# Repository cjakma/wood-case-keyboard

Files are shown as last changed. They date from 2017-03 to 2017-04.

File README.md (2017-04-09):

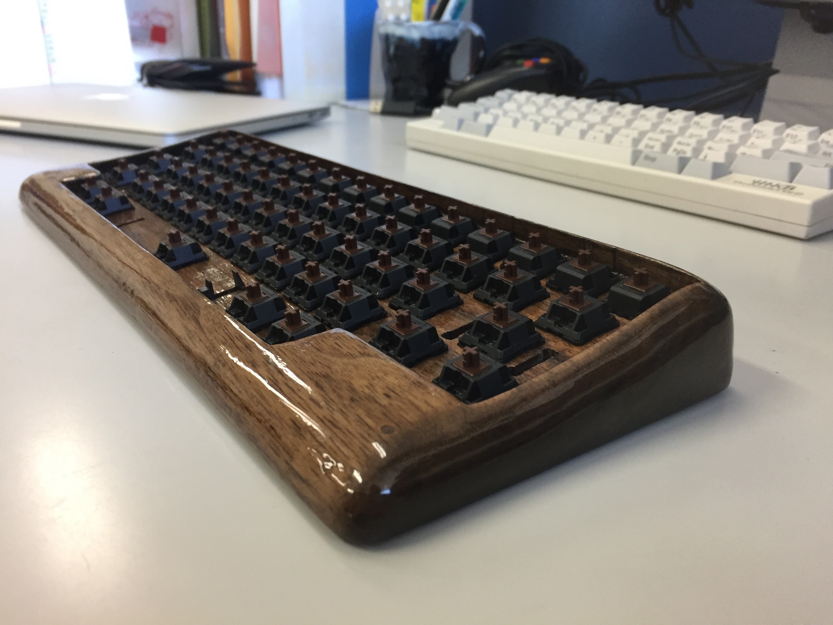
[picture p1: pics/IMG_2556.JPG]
look0

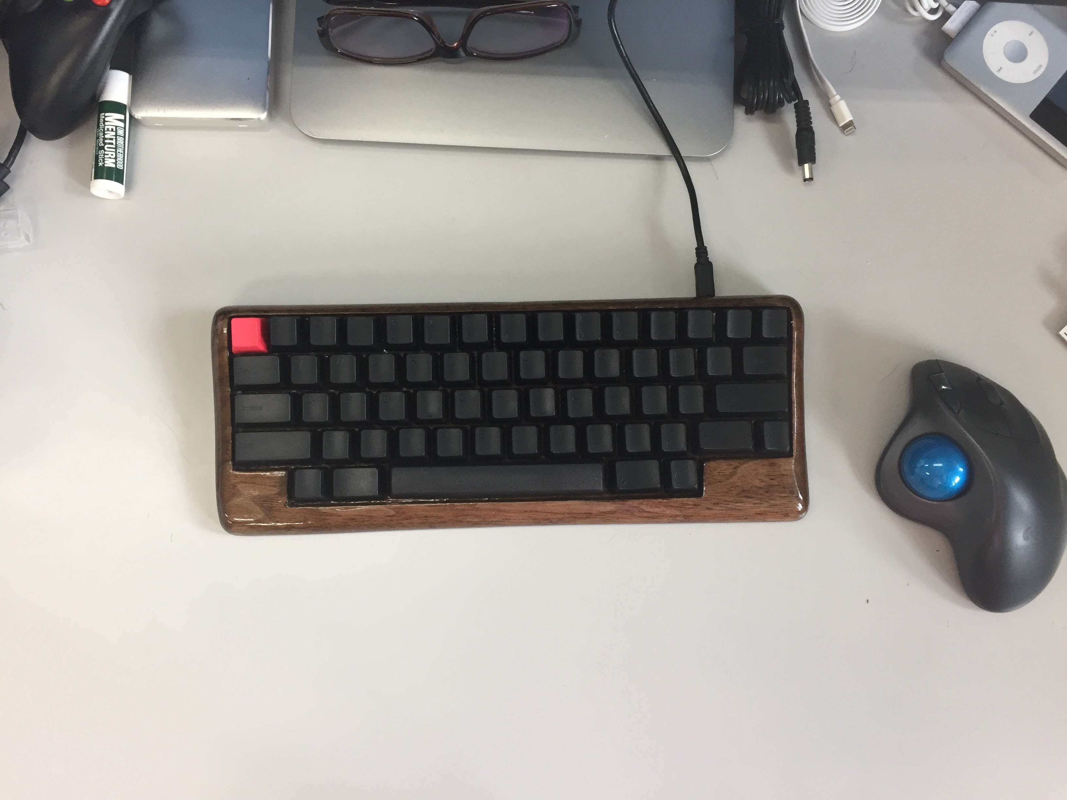
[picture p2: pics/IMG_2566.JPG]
look1

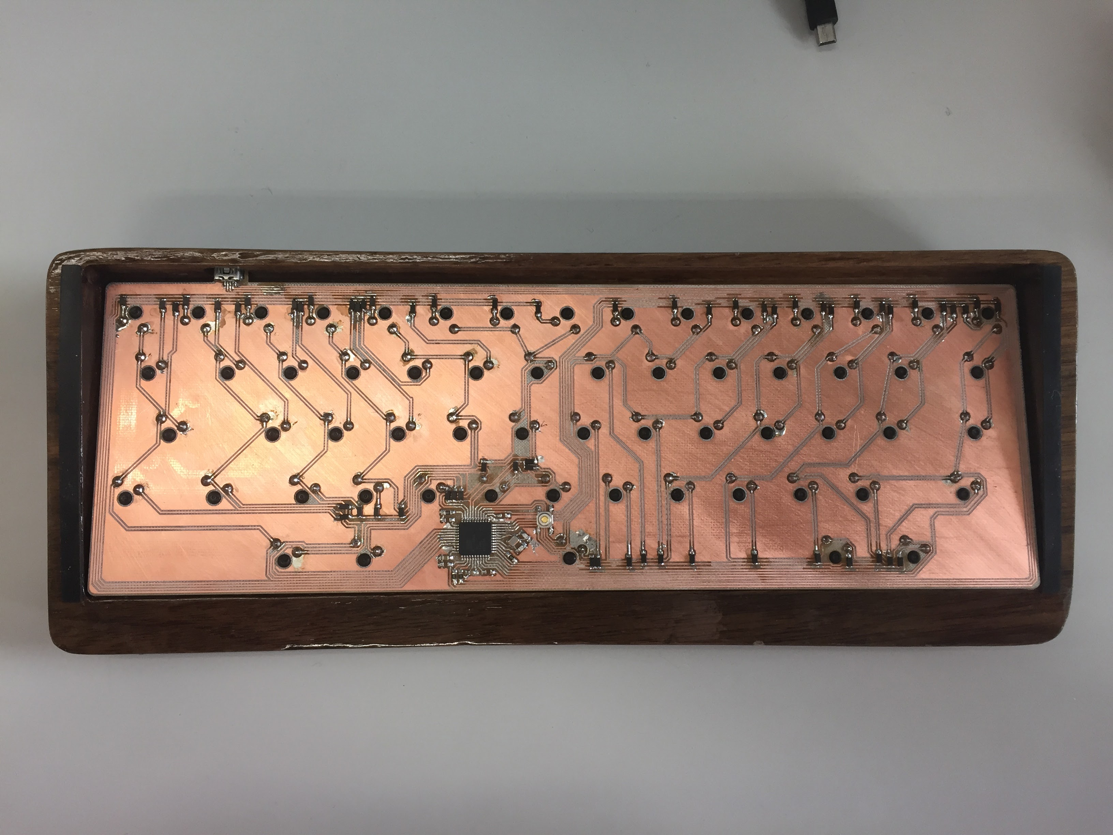
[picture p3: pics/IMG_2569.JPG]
look2


# Brief
This is a hobby project, to make a copy of HHKB made of wood,
but not limited to it. It is fully customizable, parameterized
toolchain to generate a keyboard case.

## Features
- Made of wood
- Nice curved shape
- Customizable layout and shape (compatible with <http://www.keyboard-layout-editor.com/>)
- Open bottom (it minimizes overall height and you can show off your beautiful PCB!)
- Compatible with most PCBs built with SMD components(?)

## BOM
| Name | Quantities | Price | Note |
| --- | --- | ----- | --- |
| 36x130x330mm walnut block | 1 | 2,080 JPY | <http://shop.woodworks-marutoku.com/products/muku/item/m003.php> |
| Cherry mx brown switches  | 60 | 4,640 JPY | |
| PCB | 1 | 2,908 JPY | DIY <https://github.com/jinhwanlazy/hhkb-pcb> |
| Keycaps | 1 | 50 USD | Special order from <http://www.maxkeyboard.com/> |

# Dependancies
- python3
- [python-shapely](https://pypi.python.org/pypi/Shapely)
- [Openscad](http://www.openscad.org/) - nightly version is recommended
- [OskarLinde/scad-utils](https://github.com/OskarLinde/scad-utils)
- [openscad/list-comprehension-demos](https://github.com/openscad/list-comprehension-demos)

# Build
Open `model/common.sacd` and modify parameters. You have to set `block_size`
properly even if you don't want to change anything. See
[Customization](#customization) section for details.

Following command will generate all 3D and 2D models you need, in
`stl` and `dxf` format, under `out` directory. Once you excecute `make` 
successfuly, you can open `model/preview.scad` and see how it will look
like.

    git clone https://github.com/jinhwanlazy/wood-case-keyboard
    cd wood-case-keyboard
    make

In OSX, you have to specify full path of openscad.

    make SCAD=/Applications/OpenSCAD.app/Contents/MacOS/OpenSCAD

# Customization
## Layout
Layout definitions are located under `layout` directory. They are 
compatible with <http://www.keyboard-layout-editor.com/>. 
You can feed one of them like this.

    make clean
    make LAYOUT=layout/plank.layout

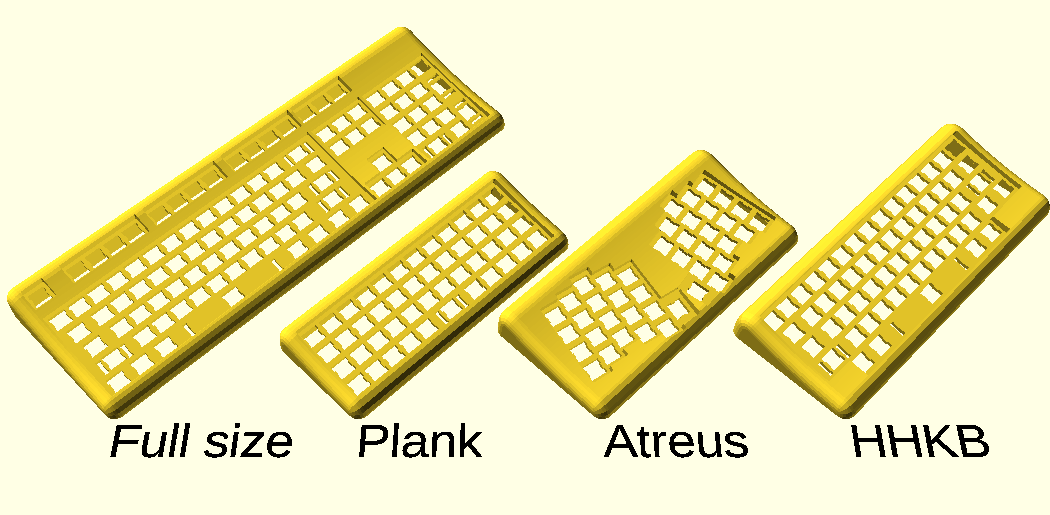
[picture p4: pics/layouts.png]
layouts


## Parameters
preparing...

# Instruction
I used a [Shapeoko1](https://www.shapeoko.com/shapeoko1.html) for milling
, and [PyCam](http://pycam.sourceforge.net/) to generate 
toolpaths. And it was painfull job.
I have spent a lot of time to properly calibrate machine but
still encountered number of hardware problems(slipping bits, burning wood, missing steps, etc). 
I had to manually edit gcodes generated by PyCam. sometimes I forgot to do it,
and it came back with disasters. Most of them are covered with sanding process,
but some were unreversible, especially, you can see a hole at bottom right corner of the
case in the first picture.
I had to make monkeypatchs everytime something goes wrong. 
I highly recommend you to use commercial grade toolchain or just talk with manufacturer. 
I'll leave here very brief steps I have followed, rather than full instruction. 

0. I started with 330x130x34mm walnut block.
1. Print `back_holder.stl` and `tilt_holder.stl` with 3D printer.
2. Fix wood block on CNC mill, and carve it with `base.stl`. I had to split it
two pieces, due to limitaion of build space. 
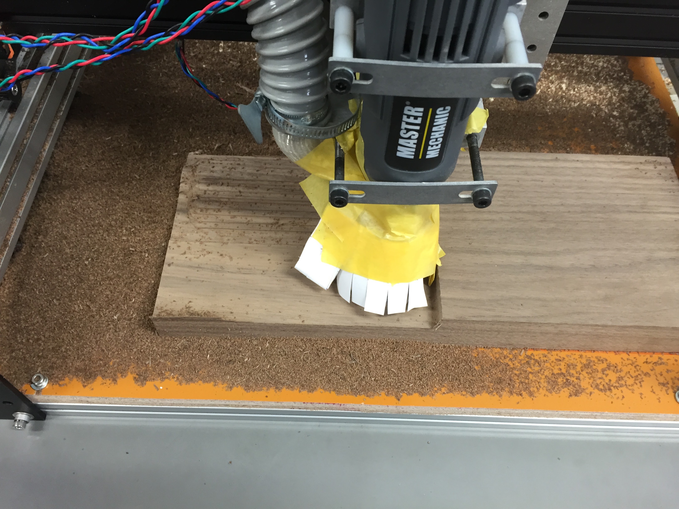
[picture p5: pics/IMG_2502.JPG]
ins2

3. Fix a pair of `tilt_holder` with screw at bottom of the wood block.
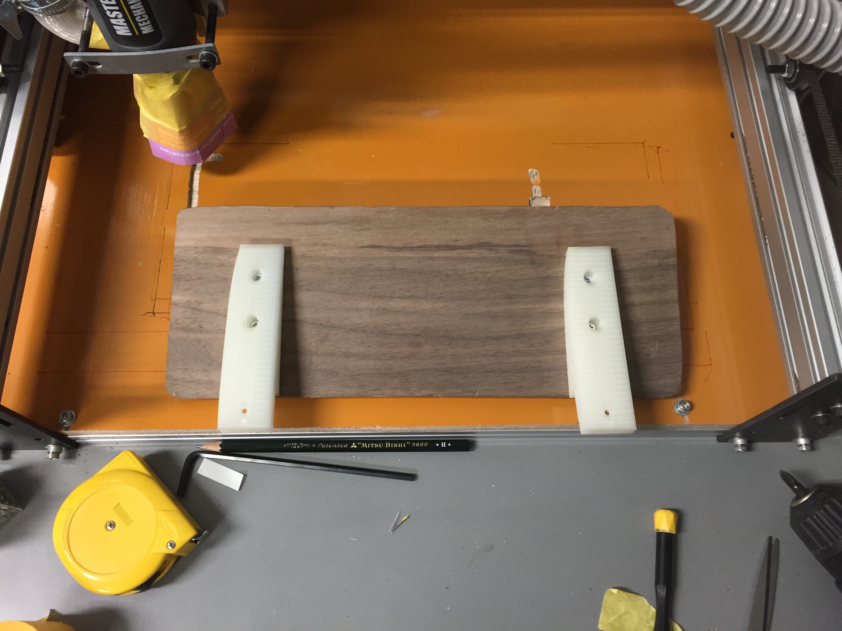
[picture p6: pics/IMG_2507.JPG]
ins3

4. Place wood block again, and cut it with `top_cutout.dxf`.
Cut depth is `lip_depth`mm from the highest point of the woodblock. It is
defined in `common.scad`.
The size of the model is arbitrary. Ignore the contour.
You have to cutout only pockets of the model.
The origin of the model is set to bottom leftmost key position.
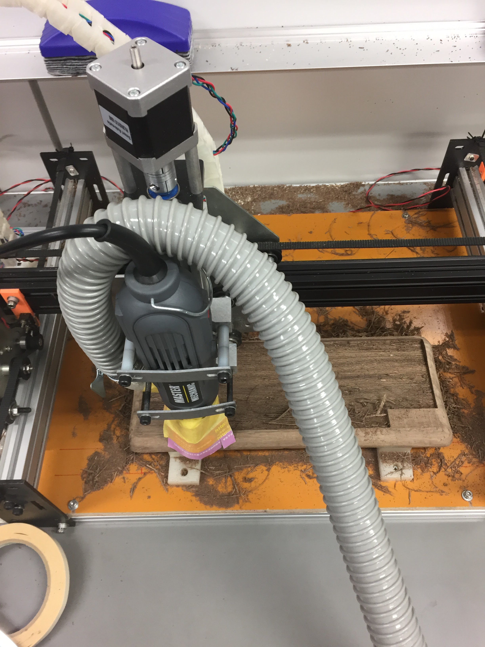
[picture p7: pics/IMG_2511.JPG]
ins4

5. Cut with `plate.dxf`. Again, ignore contour, cutout pockets. Cut down 6mm
   from the surface of previous cut.
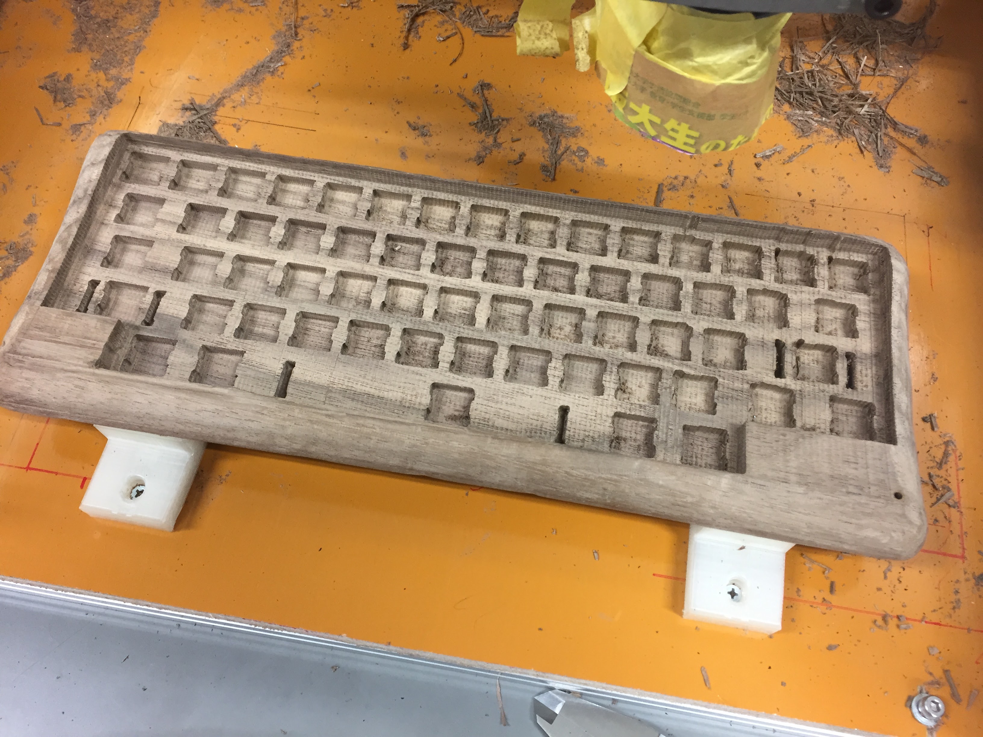
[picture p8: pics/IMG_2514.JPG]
ins5

6. Take off the block and fix it with `back_holder`, then cut it with
   `bottom_cutout.dxf`. Cut down until the thickness of top becomes 5mm.
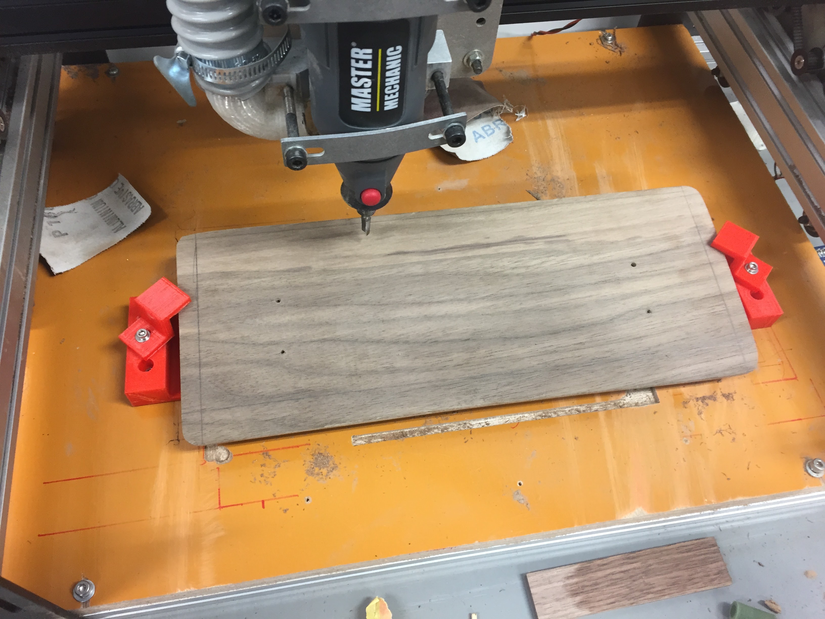
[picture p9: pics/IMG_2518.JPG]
ins6

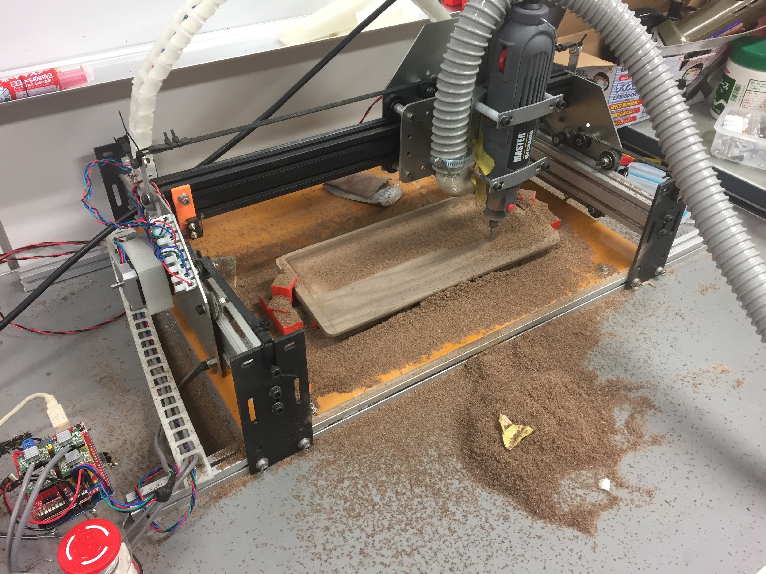
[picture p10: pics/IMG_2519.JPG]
ins7

7. Take off the result. 
8. Make a hole at back, so that USB connector can show up.
   I did it by hand with dremel.
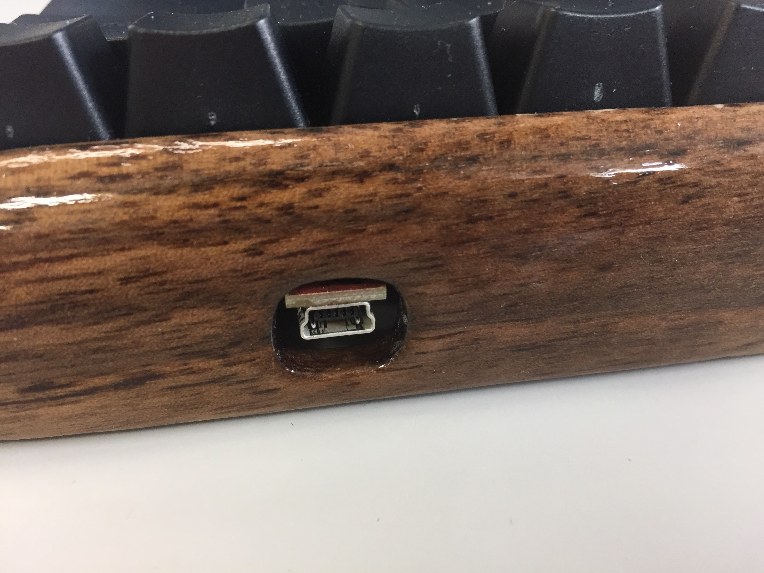
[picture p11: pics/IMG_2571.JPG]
ins8

9. Sand and finish it with oil stain and varnish.

## Caveats
- The bottom surface is not flat. I started with flat wood block, but
  it distorted itself while milling.
- Open bottom may not a good idea in a long term. You always have to worry
  about conductive things on your desk.
- Layout support is quite limited at this point. It can parse only subset of
  [keyboard-layout-editor](http://www.keyboard-layout-editor.com/)'s syntax.
  Result maybe ugly with layouts other than 60% board.
- There seems to be errors in `base.stl` model. They are automatically fixed in most
  tools but it can be problametic in some cases. 
- You have to source PCB yourself unless you like [HHKB layout](https://github.com/jinhwanlazy/hhkb-pcb). 
- Note that the result on the pictures became smaller than 3D model.
  I had to cut it little more to hide my mistakes.
- There are some different types of [6u spacebar](https://deskthority.net/wiki/Space_bar_dimensions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).
  I hardcoded one of them in `model/plate.scad`. You have to manually modify it
  if you want something else.

[look0]: https://github.com/jinhwanlazy/wood-case-keyboard/raw/master/pics/IMG_2556.JPG "look0"
[look1]: https://github.com/jinhwanlazy/wood-case-keyboard/raw/master/pics/IMG_2566.JPG "look1"
[look2]: https://github.com/jinhwanlazy/wood-case-keyboard/raw/master/pics/IMG_2569.JPG "look2"
[ins2]: https://github.com/jinhwanlazy/wood-case-keyboard/raw/master/pics/IMG_2502.JPG "ins2"
[ins3]: https://github.com/jinhwanlazy/wood-case-keyboard/raw/master/pics/IMG_2507.JPG "ins3"
[ins4]: https://github.com/jinhwanlazy/wood-case-keyboard/raw/master/pics/IMG_2511.JPG "ins4"
[ins5]: https://github.com/jinhwanlazy/wood-case-keyboard/raw/master/pics/IMG_2514.JPG "ins5"
[ins6]: https://github.com/jinhwanlazy/wood-case-keyboard/raw/master/pics/IMG_2518.JPG "ins6"
[ins7]: https://github.com/jinhwanlazy/wood-case-keyboard/raw/master/pics/IMG_2519.JPG "ins7"
[ins8]: https://github.com/jinhwanlazy/wood-case-keyboard/raw/master/pics/IMG_2571.JPG "ins8"
[layouts]: https://github.com/jinhwanlazy/wood-case-keyboard/raw/master/pics/layouts.png "layouts"

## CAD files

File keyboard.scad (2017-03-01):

use <list-comprehension-demos/sweep.scad>
use <scad-utils/transformations.scad>
use <scad-utils/shapes.scad>
use <scad-utils/morphology.scad>
include <params.scad>

inch = 25.4;
unit = 19.05;

lead_margin = 2;
lip_depth = 9.5;
top_cutout_depth = lip_depth        +
                   5     /*switch*/ +
                   1.65  /*pcb*/    +
                   lead_margin;
front_height= 19.5;
case_tilt=10;
plate_tilt=9.5;
round = 6;
margin=[9, 3];

screw_holes = [
    [0.2, 2.0],
    [14.8, 2.5],
    [1.375, 3.5],
    [6.75, 2.5],
    [9.5, 0.5],
    [13.625, 3.5]
]*unit;

x = [1, 0, 0];
y = [0, 1, 0];
z = [0, 0, 1];


/* plate_width = plate_width - 10; */


module case(
        plate_width=plate_width,
        plate_length=plate_length,
        case_tilt=case_tilt,
        front_height=front_height,
        margin=margin,
        round=round)
{
    R = 400;
    h1 = front_height;
    h2 = h1 + plate_width*sin(case_tilt);
    w = plate_width*cos(case_tilt);
    echo("h1", h1); 
    echo("h2", h2); 
    
    p = sq(h2-h1)/sq(w);
    q = (sq(w)+sq(h2)-sq(h1))/(2*(h2-h1));
    r = p+1;
    s = -2*(p*q+h1);
    t = p*sq(q)+sq(h1)-sq(R);
    b = (-s+sqrt(sq(s)-4*r*t))/(2*r);
    a = -sqrt(sq(R)-sq(h1-b));

    o0 = 5;
    o2 = 4;

    m1 = margin[1];
    m2 = margin[0];

    function sq(x) = pow(x, 2);
    function t1(x) = b - sqrt(sq(R) - sq(x-a))-round;
    function t0(x) =
        /* let(b = margin) let(a = d1(0) / (2*(0-b))) let(c = t1(0) - a*sq(0-b)) */
        /* a*sq(x-b)+c; */
        let(b = m1)
        let(a = d1(0) / (o0*pow(-b, o0-1)))
        let(c = t1(0) - a*pow(-b, o0))
        a*pow(x-b, o0)+c;
    function t2(x) = 
        let(b = w+m1)
        let(a = d1(w) / (o2*pow(w-b, o2-1)))
        let(c = t1(w) - a*pow(w-b, o2))
        a*pow(x-b, o2)+c;
    function d1(x) = (x-a) / sqrt(sq(R) - sq(x-a));
    function d0(x) = 
        let(b = m1)
        let(a = d1(0) / (o0*pow(-b, o0-1)))
        let(c = t1(0) - a*pow(-b, o0))
        o0*a*pow(x-b, o0-1);
    function d2(x) = 
        let(b = w+m1)
        let(a = d1(w) / (o2*pow(w-b, o2-1)))
        let(c = t1(w) - a*pow(w-b, o2))
        o2*a*pow(x-b,o2-1);
    function traj(x) =
        x <= 0 ? t0(x) :
        x <= w ? t1(x) : t2(x);
    function devi(x) = 
        x <= 0 ? d0(x) :
        x <= w ? d1(x) : d2(x);
    half_circle = [for (i = [0 : 180/20 : 180]) [cos(i), sin(i)]];

    module side() {
        function shape(r) = [for (xy = half_circle) [xy[0]*r, xy[1]*r]];
        interval= concat(
                [for (i=[-30:40/80:10]) i],
                [for (i=[10:(plate_width-20)/60:plate_width-10]) i],
                [for (i=[plate_width-10:40/80:plate_width+30]) i]);
        transform1 = [for (i = interval)
            translation([0, i, traj(i)])
            * rotation((-90+atan(devi(i)))*x)
            * rotation(180*z)
        ];
        transform2 = [for (i = interval)
            translation([0, i, traj(i)-round*3])
            * rotation(-90*x)
            * scaling([1, 3, 1])
        ];
        intersection() {
            union() {
                sweep(shape(round), transform1);
                sweep(square(round*2), transform2);
            }
            translate([-round*2, -50]) cube([4*round, w+100, 50]);
        }
    }
    module proj() {
        projection() rotate(-90*y) side();
    }
    translate(-m2*x) side();
    rotate(90*y) translate(-m2*z)
        linear_extrude(height=plate_length+2*m2) proj();
    translate((plate_length+m2)*x) side();
}

module top_cutout1()
{
    translate(plate_width*y) outset(d=0.3, $fn=10) polygon(plate_coords);
}

module top_cutout2()
{
    rounding(r=3.5, $fn=20)
    difference() {
        translate(plate_width*y) inset(r=2, $fn=10) polygon(plate_coords);
        for (i = [0 : 1 : len(screw_holes)-1]) translate(screw_holes[i]) circle(r=5);
    }
}

module top_cutout3()
{
    size = [11, 11];
    translate([unit, plate_width]) translate(-size+size[0]/2*x) square(size);
}

module top_drill()
{
    for (i = [0 : 1 : len(screw_holes)-1]) {
        translate(screw_holes[i]) circle(d=2.4, $fn=10);
    }
}

module bottom_cutout()
{
    outset(d=1, $fn=10)
    polygon([[0, 0], [plate_length, 0],
            [plate_length, plate_width], [0, plate_width]]);
}

module pcb()
{
    linear_extrude(height=1.65)
    translate(plate_width*y) polygon(plate_coords);
}

module plate()
{
    linear_extrude(height=1.5)
    difference()
    {
        /* polygon([[0, 0], [plate_length, 0], */
                /* [plate_length, plate_width], [0, plate_width]]); */
        translate(plate_width*y) polygon(plate_coords);
        switch_cutout();
    }
}

module switch_cutout()
{
    inch = 25.4;
    module mirrored(d) {
        children();
        mirror(d) children();
    }
    module stabil() {
        translate([-0.131*inch, -0.26*inch])
        square([0.262*inch, 0.484*inch]);
    }
    module cutout(unit) {
        square(0.551*inch, true);
        mirrored(x) {
            if (2 <= unit && unit < 3)   {translate(-0.94/2*inch*x) stabil(); } 
            if (3 <= unit && unit < 4.5) {translate(-1.50/2*inch*x) stabil(); } 
            if (unit == 6)               {translate(43.5*x) stabil(); }
        }
    }
    translate(plate_width*y)
    for (sw = switch_info) {
        pos = sw[0];
        rot = sw[1];
        unit = sw[2];
        row = sw[3];
        translate(pos) rotate(rot) cutout(unit);
    }
}

module keycaps()
{
    module R1U100() { import("./keycaps/SA_R1U100.stl"); }
    module R2U100() { import("./keycaps/SA_R2U100.stl"); }
    module R2U150() { import("./keycaps/SA_R2U150.stl"); }
    module R3U100() { import("./keycaps/SA_R3U100.stl"); }
    module R3U150() { import("./keycaps/SA_R3U150.stl"); }
    module R3U175() { import("./keycaps/SA_R3U175.stl"); }
    module R3U225() { import("./keycaps/SA_R3U225.stl"); }
    module R3U400() { import("./keycaps/SA_R3U400.stl"); }
    module R3U600() { import("./keycaps/SA_R3U600.stl"); }
    module R4U100() { import("./keycaps/SA_R4U100.stl"); }
    module R4U150() { import("./keycaps/SA_R4U150.stl"); }
    module R4U175() { import("./keycaps/SA_R4U175.stl"); }
    module R4U225() { import("./keycaps/SA_R4U225.stl"); }

    translate(plate_width*y)
    for (sw = switch_info) {
        pos = sw[0];
        rot = sw[1];
        unit = sw[2];
        row = sw[3];
        translate(pos) rotate(rot)
        if (row == 0) {
            if (unit == 1)         R1U100();
        } else if (row == 1) {     
            if (unit == 1)         R2U100();
            else if (unit == 1.5)  R2U150();
        } else if (row == 2) {     
            if (unit == 1)         R3U100();
            else if (unit == 1.5)  R3U150();
            else if (unit == 1.75) R3U175();
            else if (unit == 2.25) R3U225();
        } else if (row == 3) {     
            if (unit == 1)         R4U100();
            else if (unit == 1.5)  R4U150();
            else if (unit == 1.75) R4U175();
            else if (unit == 2.25) R4U225();
        } else if (row == 4) {     
            if (unit == 1)         R3U100();
            else if (unit == 1.5)  R3U150();
            else if (unit == 4)    R3U400();
            else if (unit == 6)    R3U600();
            else if (unit == 6.25) R3U625();
        }
    }
}

module wood_block()
{
    cube([330, 130, 36]);
}

module preview() {
    color([70, 50, 15]/255)
    difference() {
        translate(3*y)
        case(plate_width=plate_width-7);

        translate(front_height*z) rotate(plate_tilt*x)
        translate(-(top_cutout_depth-lead_margin)*z)
        linear_extrude(height=top_cutout_depth+1)
        rounding(d=1, $fn=12)
        top_cutout1();

        translate(front_height*z) rotate(plate_tilt*x)
        translate(-(top_cutout_depth)*z)
        linear_extrude(height=top_cutout_depth+1)
        top_cutout2();

        translate(front_height*z) rotate(plate_tilt*x)
        translate(-(top_cutout_depth+4.1)*z)
        linear_extrude(height=top_cutout_depth+1)
        top_cutout3();

        translate(front_height*z) rotate(plate_tilt*x)
        translate(-(top_cutout_depth)*z)
        linear_extrude(height=top_cutout_depth+1)
        top_drill();
    }
    %color("green")
    translate(front_height*z)
    rotate(plate_tilt*x)
    translate(-(top_cutout_depth-1.65)*z)
    pcb();

    color("silver")
    translate(front_height*z)
    rotate(plate_tilt*x)
    translate(-(top_cutout_depth-1.65-5)*z)
    plate();

    translate(front_height*z)
    rotate(plate_tilt*x)
    translate(-(lip_depth-6.6)*z)
    color([255, 255, 204]/255)
    keycaps();

    /* translate([-19, -15, 0]) */
    /* % wood_block(); */
}


/* rotate(-plate_tilt*x) */
/* intersection() */
/* { */
    /* translate([0, 15, 0]) preview(); */
    /* translate(20*x) cube([60, 150, 50]); */
/* } */

case();
/* translate([0, 15, 0]) preview(); */
/* top_cutout3(); */
/* top_cutout2(); */
/* switch_cutout(); */
/* switch_cutout(); */
/* color("red") top_drill(); */
/* %pcb(); */
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

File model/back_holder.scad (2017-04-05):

include <common.scad>

module back_holder()
{
    mirror(x) cube([20, 60, 16]);
    cube([20, 60, 4]);
    translate(20*x)
    difference()
    {
        cube([20, 60, 16]);
        translate([10, 15, 0]) screw_hole();
        translate([10, 45, 0]) screw_hole();
        translate([10, 30, -2]) {
            cylinder(d=3.1, h=20, $fn=12);
            cylinder(d=6.3, h=13, $fn=6);
        }
    }

    module screw_hole()
    {
        translate(2*z) {
            mirror(z) translate(-0.1*z) cylinder(d=3.1, h=20, $fn=20);
            cylinder(d1=3.1, d2=8, h=2.5, $fn=20);
            translate(2.5*z) cylinder(d=8, h=20, $fn=20);
        }
    }
}

module clip()
{
    difference()
    {
        cube([20, 20, 5]);
        translate([10, 10, -1]) hull()
        {
            $fn=24;
            translate(1.5*x) cylinder(d=3.2, h=7); 
            translate(-1.5*x) cylinder(d=3.2, h=7); 
        }
    }
    translate(20*x) rotate(-80*y)
    {
        cube([20, 20, 5]);
        translate(15*x) rotate(90*y) cube([15, 20, 5]);
    }
}

module print()
{
    rotate(90*x) back_holder();
    translate(30*y) rotate(90*x) back_holder();
    translate([50, 0, 0]) rotate(90*x) clip();
    translate([50, 30, 0]) rotate(90*x) clip();

}

module preview()
{
    translate(20*z)
       rotate(180*z) rotate((180-tilt())*x) base();
    translate(40*y)
        back_holder();

    translate([40, 80, 17])
    rotate(180*z)
    rotate(-10*y)
    clip();
}

print();

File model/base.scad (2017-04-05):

use <list-comprehension-demos/sweep.scad>
use <scad-utils/transformations.scad>
use <scad-utils/shapes.scad>
include <common.scad>

render()
translate(-[xmin(), ymin()]) base();

module base()
{
    echo("size: ",[xmax()-xmin(), ymax()-ymin()]);
    echo("x: ", [xmin(), xmax()]);
    echo("y: ", [ymin(), ymax()]);
    echo(pow(2, 1/2));

    module side() {
        function shape(r) = [for (xy = half_circle) [xy[0]*r, xy[1]*r]];
        interval= concat(
                [for (i=[-10:20/30:10]) i],
                [for (i=[10:(py-20)/20:py-10]) i],
                [for (i=[py-10:20/20:py+10]) i]);
        transform1 = [for (i = interval)
            translation([0, i, traj(i)])
            * rotation((-90+atan(devi(i)))*x)
            * rotation(180*z)
        ];
        transform2 = [for (i = interval)
            translation([0, i, traj(i)-roundness*3])
            * rotation(-90*x)
            * scaling([1, 3, 1])
        ];
        intersection() {
            union() {
                sweep(shape(roundness), transform1);
                sweep(square(roundness*2), transform2);
            }
            translate([-roundness*2, -50]) cube([4*roundness, w+100, 50]);
        }
    }
    module proj() {
        projection() rotate(-90*y) side();
    }

    translate(-mx*x) side();
    rotate(90*y) translate(-mx*z)
        linear_extrude(height=px+2*mx) proj();
    translate((px+mx)*x) side();
    %translate([xmin(), ymin()]) cube([xmax()-xmin(), ymax()-ymin(), 36]);
}

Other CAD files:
case.scad
model/bottom_cutout.scad
model/common.scad
model/plate.scad
model/preview.scad
model/shape.scad
model/tilt_holder.scad
model/top_cutout.scad

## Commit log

2017-02-16 initial commit; Outer shape of case is done
    [case.scad, params.scad]
2017-02-20 add keycap preview
    [SA_R1U100.stl, SA_R2U100.stl, SA_R2U150.stl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]
2017-02-20 add pcb modules
2017-02-20 some more keycaps
    [SA_R3U175.stl, SA_R3U225.stl, SA_R4U175.stl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]
2017-02-20 round cutout
    [case.scad]
2017-02-22 add kicad lib
2017-02-22 pcb is almost done
    [case.scad, hhkb_400.csv, hhkb_400.kicad_pcb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]
2017-02-22 add gerber files
    [hhkb_400-B.Cu.gbr, hhkb_400-Edge.Cuts.gbr, hhkb_400-NPTH.drl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]
2017-02-22 add pcb2gcode conf
2017-02-22 add BOM, work in progress
2017-02-22 files updated
    [hhkb_400.kicad_pcb, params.scad]
2017-02-22 use jumper to represent jumper, rather than 0ohm resister
    [hhkb_400.kicad_pcb, hhkb_400.sch]
2017-03-01 add stl files
    [00_shape.stl]
2017-03-08 Lots of changes
    add instructions in readme
    rm keycaps preview
    rm legacy stl
    separate scad files for each toolpath
    update gitignore
    [00_shape.stl, SA_R1U100.stl, SA_R2U100.stl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]
2017-03-08 update readme; make room for pcb
2017-03-08 remove dupe
    [params.scad]
2017-03-08 add splitted shape
    [bottom_cutout.scad, shape.scad, shape_left.scad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]
2017-03-08 naive makefile
    [keyboard.scad]
2017-03-08 add stl and gcodes
    [bottom_cutout.stl, shape.stl, shape_left.stl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]
2017-03-08 sane offsets
    [shape_left.scad]
2017-03-08 adjust offsets
    [shape_right.scad]
2017-03-08 fix collision
    [shape_right.scad]
2017-03-08 regenerate gcodes
    [shape.stl, shape_left.stl, shape_right.stl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]
2017-03-08 add pcb gcodes
2017-03-10 add tilt holder
    [tilt_holder.scad]
2017-03-10 cut lip and slots same time
    [top_cutout.scad]
2017-03-11 add cutout margin
    [switch_cutout.scad]
2017-03-11 rename shape to base, better positioning
    [base.scad, base_left.scad, base_right.scad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]
2017-03-18 untrack stls
    [bottom_cutout.stl, top_cutout.stl]
2017-03-18 ignore kicad tmp files
2017-03-18 stop using pcb2gcode
2017-03-18 add back_holder
    [back_holder.scad]
2017-03-18 rework pcb artwork
    [hhkb.kicad_pcb, hhkb.sch, hhkb_400.sch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]
2017-03-18 rm legacy; 4u spacebar pcb
    [hhkb_400.csv, hhkb_400.kicad_pcb, hhkb_400.sch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]
2017-03-18 enlarge trace width
    [hhkb.kicad_pcb, hhkb.sch]
2017-03-19 redraw outline
    [hhkb.kicad_pcb]
2017-03-26 fix left super size
    [hhkb.kicad_pcb, hhkb.sch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]
2017-03-27 optimize some path
    [hhkb.kicad_pcb]
2017-03-28 export pcb to separate repo
    [hhkb.kicad_pcb, hhkb.sch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]
2017-03-29 mv firmware to pcb repo
2017-04-05 clean code
    [back_holder.scad, base.scad, base_left.scad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]
2017-04-05 fix preview
    [preview.scad]
2017-04-07 build prewview also
    [common.scad]
2017-04-07 fix stabilizer dimension
    [plate.scad]
2017-04-07 fix bug with vertically long switches
2017-04-07 add usb connector picture
2017-04-08 add BOM
